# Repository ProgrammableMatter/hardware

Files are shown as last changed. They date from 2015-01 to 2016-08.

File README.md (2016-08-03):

Particle Hardware Repository
----------------------------
Hardware development repository for the particle and related hardware.

## Folder content
* **pcb-projects**: pcb projects
* **freecad**: 3D Models drawn with [FreeCAD](http://www.freecadweb.org/)
* **reflow**: reflow soldering logs, charts and helper

## PCB Projects/Versions
### Particle Version 1.21
| | | |
|---|---|---|
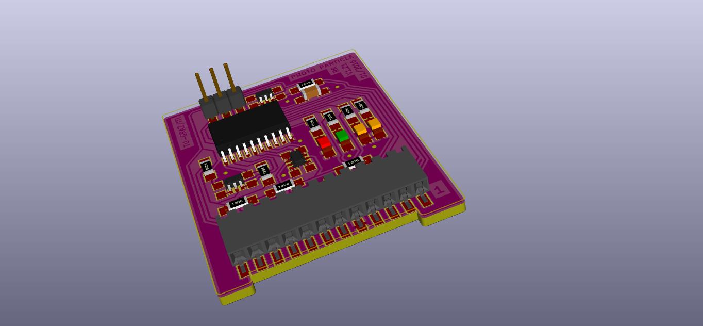
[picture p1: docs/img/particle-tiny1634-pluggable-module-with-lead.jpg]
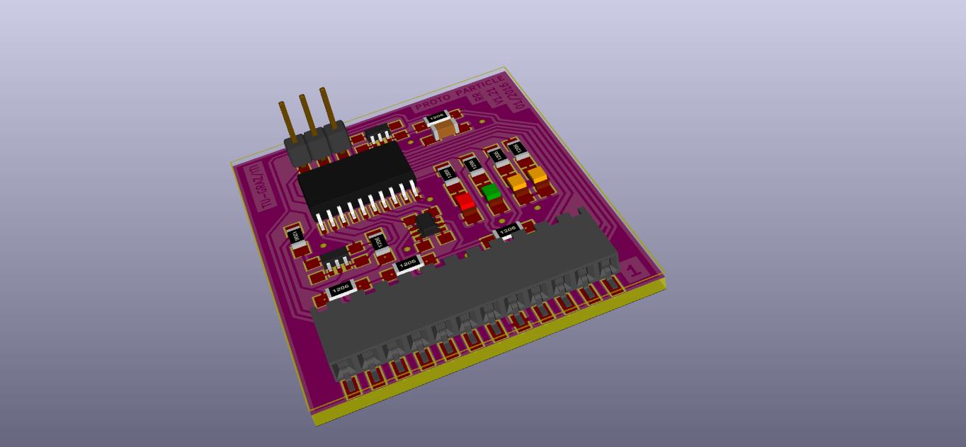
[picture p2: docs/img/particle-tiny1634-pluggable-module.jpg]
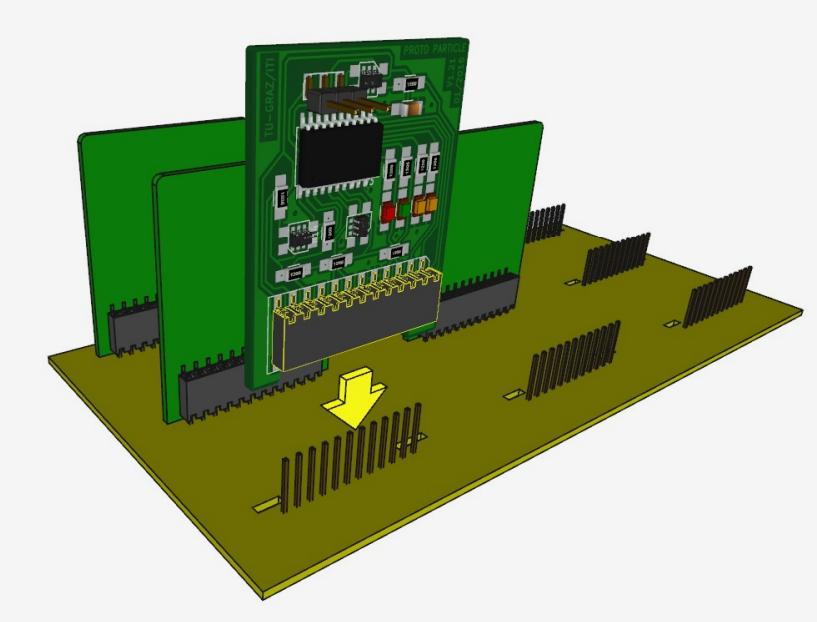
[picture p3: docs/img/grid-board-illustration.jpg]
|  |  |  |
| plugable particle with leads | pluggable particle | grid board illustartion |

### Particle version 1.1

| | | | 
|---|---|---|
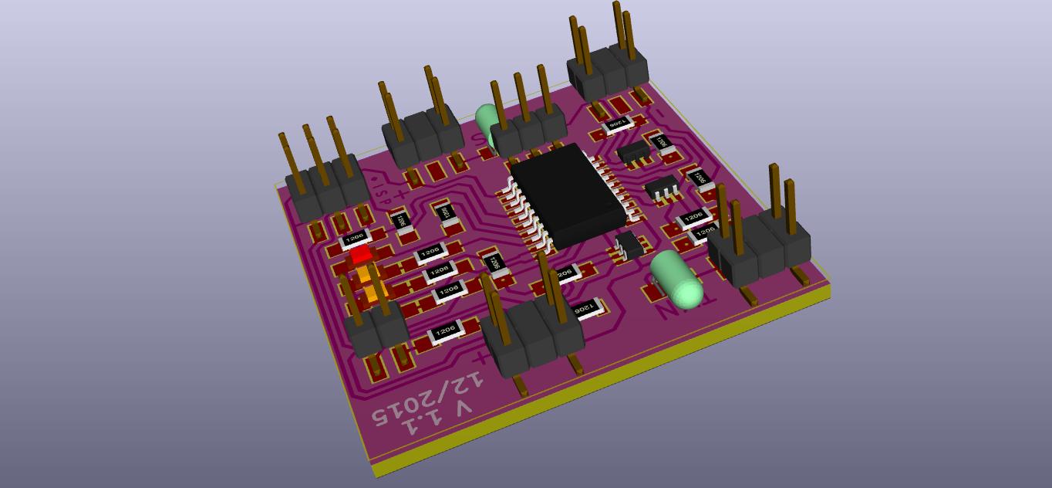
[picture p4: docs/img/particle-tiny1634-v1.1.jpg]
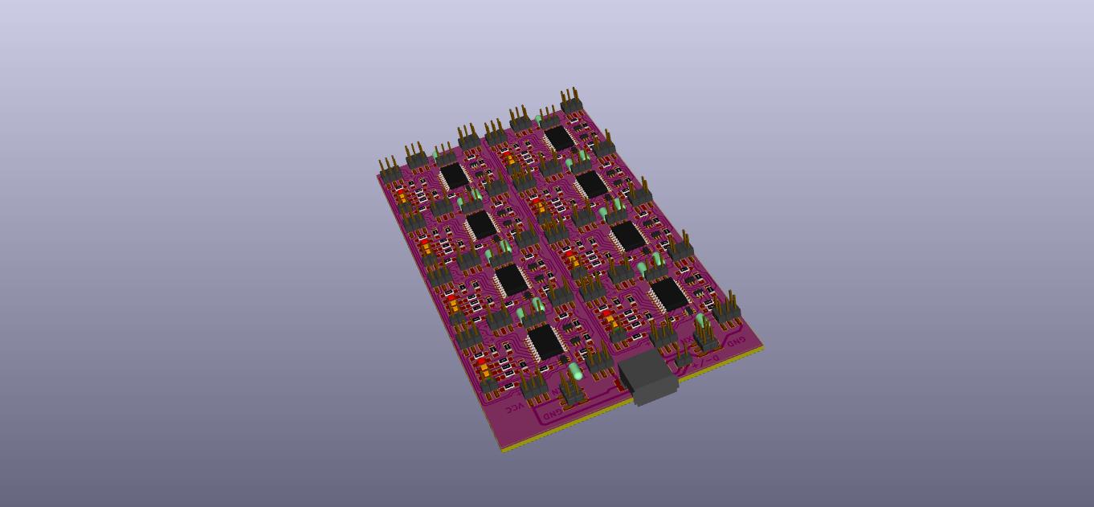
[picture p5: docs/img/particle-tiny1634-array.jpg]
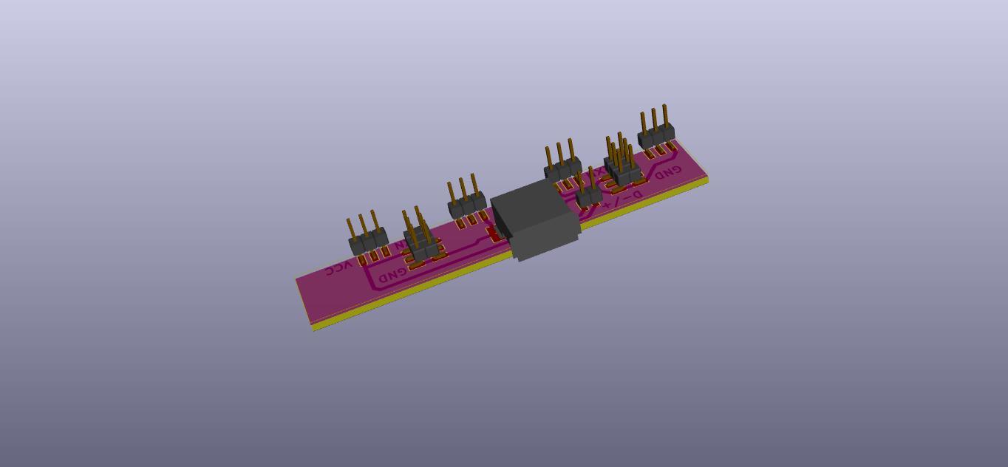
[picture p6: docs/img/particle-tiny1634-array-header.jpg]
||||
| single particle | array example | array header |
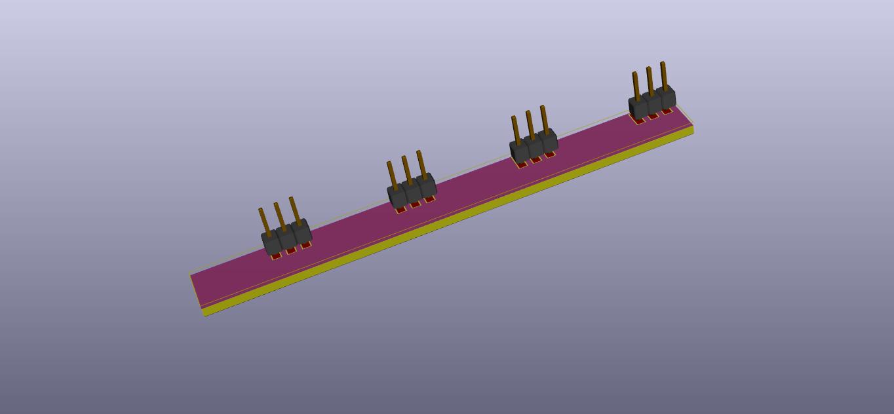
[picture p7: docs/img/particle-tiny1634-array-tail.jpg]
|  | | | 
| array tail | | |

### Particle version 0.9
|   |
|---|
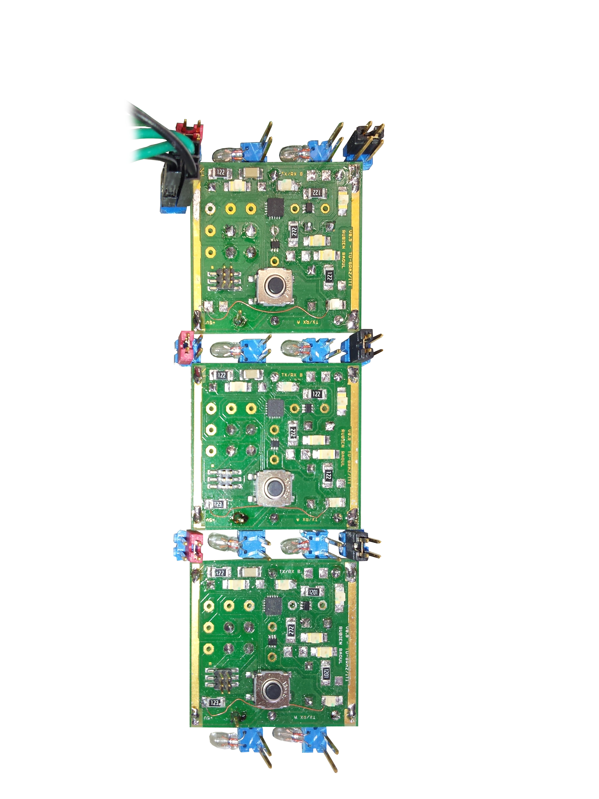
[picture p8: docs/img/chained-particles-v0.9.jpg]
||
| chain example |

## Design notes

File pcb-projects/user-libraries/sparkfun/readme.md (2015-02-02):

SparkFun Electronics Eagle Libraries
====================================

SparkFun Electronics' preferred foot prints using Eagle v6.0 or greater. 
We've spent an enormous amount of time creating and checking these footprints and parts. 
If you enjoy using this library, please buy one of our products at [SparkFun](http://www.sparkfun.com). 
Please also note that we guarantee that there are some messed up footprints in this library. 
We've tried to note which are proven and tested, but by downloading these files, you acknowledge that you are using the files at your own risk. 
We cannot be held responsible for faulty PCBs. 
Always check your parts against a 1:1 printout.

This is the complete SparkFun Electronics default foot prints for Eagle 6.0+. 
We switched to Eagle back in 2006 and have been extremely impressed with its ease of use and flexibility. 
As with any new software, it's like learning a new language and takes time. Do it. Eagle is great. 

How to Use Eagle
----------------

If you need more information about how to use Eagle, checkout our Eagle Tutorials: 

* [Installing an Eagle Library](https://learn.sparkfun.com/tutorials/how-to-install-and-setup-eagle#using-the-sparkfun-libraries)
* [Installing Eagle](https://learn.sparkfun.com/tutorials/how-to-install-and-setup-eagle)
* [Creating Schematics](https://learn.sparkfun.com/tutorials/using-eagle-schematic)
* [Creating Boards](https://learn.sparkfun.com/tutorials/using-eagle-board-layout)
* [Designing Custom Footprints](https://learn.sparkfun.com/tutorials/designing-pcbs-smd-footprints)
* [Creating Footprints from Digital Imagery](https://learn.sparkfun.com/tutorials/making-custom-footprints-in-eagle)

How to use GitHub
-----------------

If you need help getting started using git, check out our GitHub tutorials:
* [Using GitHub](https://learn.sparkfun.com/tutorials/using-github)
* [Using GitHub to Share with SparkFun](https://learn.sparkfun.com/tutorials/using-github-to-share-with-sparkfun)

The library associated with Eagle v5.11 and earlier is found [here](https://github.com/sparkfun/Old-SparkFun-Eagle-Library).

License Information
-------------------

This library is released under the [Creative Commons ShareAlike 4.0 International](https://creativecommons.org/licenses/by-sa/4.0/) license. 
**You are welcome to use this library for commercial purposes.**
For attribution, we ask that when you begin to sell your device using our footprint, you email us with a link to the product being sold. 
We want bragging rights that we helped (in a very small part) to create your 8th world wonder. 
We would like the opportunity to feature your device on our homepage.

Please consider contributing back to this library or others to help the open-source hardware community continue to thrive and grow!

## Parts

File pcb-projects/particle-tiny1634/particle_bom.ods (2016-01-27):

Id | Designator | Package | Quantity | Designation | Supplier and ref
1 | R1124,R1114,R1123,R1113,R1122,R1112,R1121,R124,R114,R123,R113,R122,R112,R121,R124,R114,R123,R113,R122,R112,R121,R1124,R1114,R1123,R1113,R1122,R1112,R1121,R1124,R1114,R1123,R1113,R1122,R1112,R1121,R124,R114,R123,R113,R122,R112,R121,R1124,R1114,R1123,R1113,R1122,R1112,R1121,R124,R114,R123,R113,R122,R112,R121,R124,R114,R123,R113,R122,R112,R121,R1111,R111,R111,R111,R111,R111,R1111,R1111,R1111 | R_1206_HandSoldering | 72 | 0R
2 | FB124,FB114,FB123,FB113,FB122,FB112,FB121,FB111 | SMD-1206_Pol | 8 | TXS-SMA
3 | P124,P114,P123,P113,P122,P112,P121,P111 | CONN-1x3 | 8 | TEST1-3
4 | P124,P114,P123,P113,P122,P112,P121,P111 | CONN-6_4-6 | 8 | RXS
5 | D124,D114,D123,D113,D122,D112,D121,D111 | R_1206_HandSoldering | 8 | STATUS1
6 | D124,D114,D123,D113,D122,D112,D121,D111 | R_1206_HandSoldering | 8 | ERROR
7 | R124,R114,R123,R113,R122,R112,R121,R124,R114,R123,R113,R122,R112,R121,R124,R114,R123,R113,R122,R112,R121,R1124,R1114,R1123,R1113,R1122,R1112,R1121,R124,R114,R123,R113,R122,R112,R121,R111,R1111,R111,R111,R111 | R_1206_HandSoldering | 40 | 1k2
8 | P124,P114,P123,P113,P122,P112,P121,P111 | CONN-6_4-6 | 8 | TXS
9 | CON124,CON114,CON123,CON113,CON122,CON112,CON121,CON111 | CONN-6 | 8 | AVR-ISP-6
10 | P124,P114,P123,P113,P122,P112,P121,P111 | CONN-1x2 | 8 | TRX-CH
11 | D124,D114,D123,D113,D122,D112,D121,D111 | R_1206_HandSoldering | 8 | HB
12 | D124,D114,D123,D113,D122,D112,D121,D111 | R_1206_HandSoldering | 8 | STATUS0
13 | Q-SOUTH124,Q-SOUTH114,Q-SOUTH123,Q-SOUTH113,Q-SOUTH122,Q-SOUTH112,Q-SOUTH121,Q-NORTH124,Q-NORTH114,Q-NORTH123,Q-NORTH113,Q-NORTH122,Q-NORTH112,Q-NORTH121,Q-CHAIN124,Q-CHAIN114,Q-CHAIN123,Q-CHAIN113,Q-CHAIN122,Q-CHAIN112,Q-CHAIN121,Q-NORTH111,Q-CHAIN111,Q-SOUTH111 | SOT-26 | 24 | DMC2700UDM-7
14 | IC124,IC114,IC123,IC113,IC122,IC112,IC121,IC111 | SOIC-20_7.5x12.8mm_Pitch1.27mm | 8 | ATTINY1634-SU
15 | P124,P114,P123,P113,P122,P112,P121,P111 | CONN-6_1-3 | 8 | TXN
16 | FB124,FB114,FB123,FB113,FB122,FB112,FB121,FB111 | SMD-1206_Pol | 8 | TXN-SMA
17 | P124,P114,P123,P113,P122,P112,P121,P111 | CONN-6_1-3 | 8 | RXN
18 | 1k2/124,1k2/114,1k2/123,1k2/113,1k2/122,1k2/112,1k2/121,1k2/111 | R_1206 | 8 | 1k2
19 | P3 | usb-30-right-angle-true-smt | 1 | USB_A | x
20 | P6 | CONN-6_4-6 | 1 | CHAIN2-TX | x
21 | P1 | CONN-6_4-6 | 1 | CHAIN1-TX | x
22 | P7 | CONN-6_4-6 | 1 | CHAIN2-RX | x
23 | P2 | CONN-6_4-6 | 1 | CHAIN1-RX | x
24 | P4 | CONN-6 | 1 | PWR-WEST | x
25 | P5 | CONN-6 | 1 | PWR-EAST | x
26 | P8 | CONN-1x2 | 1 | RS232 | x
27 | P1,P2,P3,P4 | CONN-6_1-3 | 4 | CONN_02X03 | x
 |  |  | Reference | Value | supplyer | price | needed pcs |  |  | pgks | Price / entity | price total
 |  |  | CON1 | AVR-ISP-6 | http://at.rs-online.com/web/p/leiterplatten-header/5286417/ | 2row-20pole-10pcs/pkg 10-40pcs 2.177 | 13,00 |  |  | 2,00 | 22,20 | 44,40
 |  |  | D1 | HB | http://at.rs-online.com/web/p/leds-sichtbares-licht/7269225/ | 25-100pcs 0.154 | 16,00 |  |  | 16,00 | 3,85 | 61,60
 |  |  | D2 | STATUS0 | http://at.rs-online.com/web/p/leds-sichtbares-licht/7269215/ | 25-100pcs 0.14 | 2x8 |  |  | 2,00 | 3,5 | 7,00
 |  |  | D4 | ERROR | http://at.rs-online.com/web/p/leds-sichtbares-licht/7269212/ | 25-100pcs 0.197 | 1x8 |  |  | 1,00 | 4,925 | 4,93
 |  |  | FB1 | TXN-SMA | http://at.rs-online.com/web/p/anzeigen-gluehlampen/0106458/ | <240pcs 0.733 | 2x8 |  |  | 3,00 | 7,33 | 21,99
 |  |  | IC1 | ATTINY1634-SU | http://at.rs-online.com/web/p/mikrocontroller/7617703/ | rs attiny1634R-su 2-8pcs 1.84 >10pcs 1.725 farnell attiny1634-su <10pcs 1.44 <25pcs 1.35 | 1x8 |  |  | 8,00 | 3,68 | 29,44
 |  |  | P6 | TEST1-3 | http://at.rs-online.com/web/p/leiterplatten-header/0155901/ | 5pcs-40pol/pkg pcs 1.324 | 8,00 |  |  | 3,00 | 1,35 | 4,04
 |  |  | Q-NORTH1 | DMC2700UDM-7 | http://at.rs-online.com/web/p/transistoren-mosfet/8232918/ | 20-80pcs 0.1291 >100pcs 0.132 | 2x8+2 |  |  | 2,00 | 2,64 | 5,28
 |  |  | R14 | 1k2 | http://at.rs-online.com/web/p/smd-widerstande/8071158/ | < 5pkg @ 100pcs 1.72 per pkg | 48,00 |  |  | 1,00 | 1,77 | 1,77
 |  |  |  | 0R | http://at.rs-online.com/web/p/smd-widerstande/7409104/ | <450pcs 0.016 | 80,00 |  |  | 4,00 | 0,80 | 3,20
 |  |  |  | usb a smd | http://at.farnell.com/multicomp/usb-a-s-ra-tsmt/usb-3-0-buchse-typ-a-smd/dp/2112370 | < 50pcs 0,578 | 2,00 |  |  | 1,00 | 0,578 | 0,58
 |  |  |  |  | supplyer |  |  | #pcs | €/pcs | €/pkg
 |  |  |  |  | http://at.rs-online.com/web/p/leiterplatten-header/5286417/ |  |  | 20,00 | 2,22 | 22,20
 |  |  |  |  | http://at.rs-online.com/web/p/leds-sichtbares-licht/7269225/ |  |  | 16,00 | 0,154 | 3,85
 |  |  |  |  | http://at.rs-online.com/web/p/leds-sichtbares-licht/7269215/ |  |  | 32,00 | 0,14 | 3,5
 |  |  |  |  | http://at.rs-online.com/web/p/leds-sichtbares-licht/7269212/ |  |  | 16,00 | 0,197 | 4,925
 |  |  |  |  | http://at.rs-online.com/web/p/anzeigen-gluehlampen/0106458/ |  |  | 30,00 | 0,73 | 7,33
 |  |  |  |  | http://at.rs-online.com/web/p/mikrocontroller/7617703/ |  |  | 16,00 | 1,84 | 3,68
 |  |  |  |  | http://at.rs-online.com/web/p/leiterplatten-header/0155901/ |  |  | 16,00 | 1,35 | 6,73
 |  |  |  |  | http://at.rs-online.com/web/p/transistoren-mosfet/8232918/ |  |  | 36,00 | 0,13 | 2,64
 |  |  |  |  | http://at.rs-online.com/web/p/smd-widerstande/8071158/ |  |  | 84,00 | 0,02 | 1,77
 |  |  |  |  | http://at.rs-online.com/web/p/smd-widerstande/7409104/ |  |  | 144,00 | 0,016 | 0,80
 |  |  |  |  | http://at.farnell.com/multicomp/usb-a-s-ra-tsmt/usb-3-0-buchse-typ-a-smd/dp/2112370 |  |  | 2,00 | 0,578 | 5,78
 |  |  |  |  | http://at.rs-online.com/web/p/usb-typ-a-steckverbinder/7187214/ |  |  | 2,00 | 2,87

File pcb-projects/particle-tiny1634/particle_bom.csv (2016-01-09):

Reference | Value | supplyer | price | needed pcs | needed pcs/pkg | Price / entity | price total
CON1 | AVR-ISP-6 | http://at.rs-online.com/web/p/leiterplatten-header/5286417/ | 2row-20pole-10pcs/pkg 10-40pcs 2.177 | 6pcs for 8 | 1 | 2,177 | 2,177
D1 | HB | http://at.rs-online.com/web/p/leds-sichtbares-licht/7269225/ | 25-100pcs 0.154 | 1x8 | 8 | 0,154 | 1,232
D2 | STATUS0 | http://at.rs-online.com/web/p/leds-sichtbares-licht/7269215/ | 25-100pcs 0.14 | 2x8 | 16 | 0,14 | 2,24
D4 | ERROR | http://at.rs-online.com/web/p/leds-sichtbares-licht/7269212/ | 25-100pcs 0.197 | 1x8 | 8 | 0,197 | 1,576
FB1 | TXN-SMA | http://at.rs-online.com/web/p/anzeigen-gluehlampen/0106458/ | <240pcs 0.733 | 2x8 | 16 | 0,733 | 11,728
IC1 | ATTINY1634-SU | http://at.rs-online.com/web/p/mikrocontroller/7617703/ | rs attiny1634R-su 2-8pcs 1.84 >10pcs 1.725 farnell attiny1634-su <10pcs 1.44 <25pcs 1.35 | 1x8 | 8 | 1,84 | 14,72
P6 | TEST1-3 | http://at.rs-online.com/web/p/leiterplatten-header/0155901/ | 5pcs-40pol/pkg pcs 1.324 | 1.6pcs | 1 | 6,6 | 6,6
Q-NORTH1 | DMC2700UDM-7 | http://at.rs-online.com/web/p/transistoren-mosfet/8232918/ | 20-80pcs 0.1291 >100pcs 0.132 | 2x8+2 | 18 | 0,132 | 2,376
R14 | 1k2 | http://at.rs-online.com/web/p/smd-widerstande/8071158/ | < 5pkg @ 100pcs 1.72 per pkg | 5x8 | 1 | 1,7 | 1,7
 |  | http://at.rs-online.com/web/p/smd-widerstande/7409104/ | <450pcs 0.016 | 7x8+2x2 | 60 | 0,016 | 0,96
 |  |  |  |  |  |  | 45,309 | = total sum
 | usb a smd | http://at.farnell.com/multicomp/usb-a-s-ra-tsmt/usb-3-0-buchse-typ-a-smd/dp/2112370 | < 50pcs 0,578 | 1 | 10 | 0,578 | 5,8

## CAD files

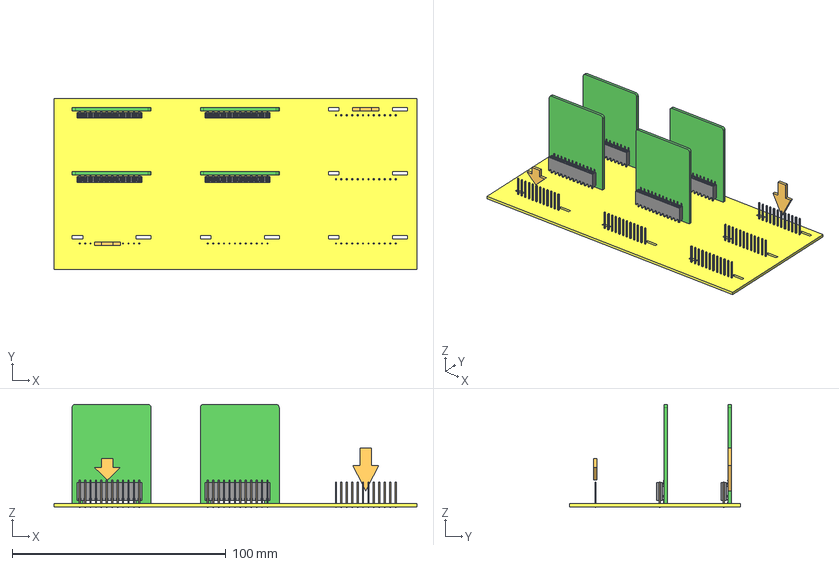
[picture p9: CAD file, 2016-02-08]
freecad/proto-pcb-gridboard-sketch.fcstd
170.0 x 80.0 x 48.4 mm
grid-board
Clone of Clone of Pad003

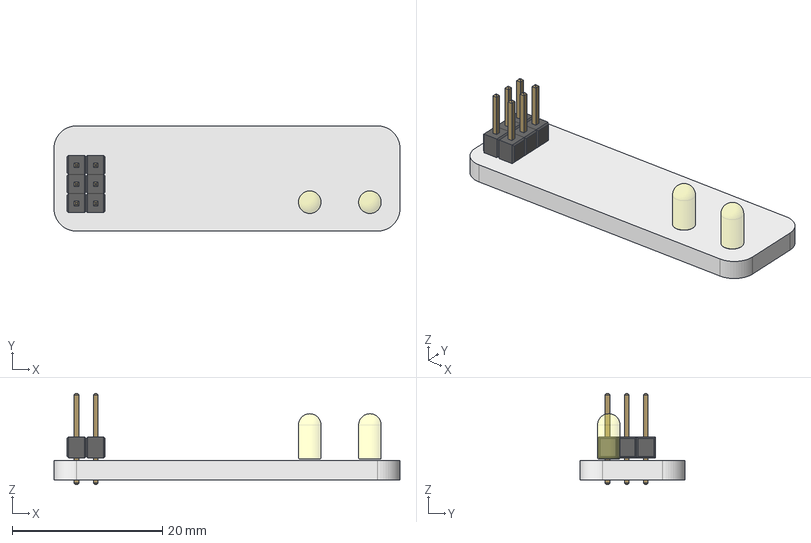
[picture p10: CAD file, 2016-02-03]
freecad/grid-board-particle-connector.fcstd
46.0 x 14.0 x 12.2 mm
bulb001
bulb002

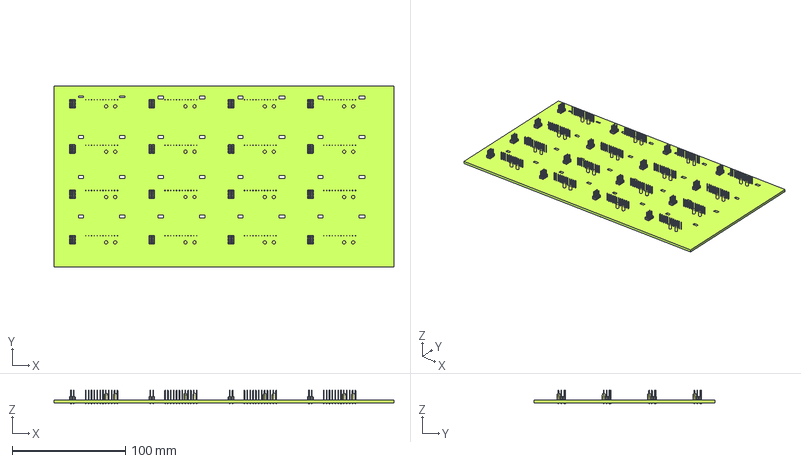
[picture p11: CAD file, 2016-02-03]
freecad/proto-pcb-gridboard-vis.fcstd
300.0 x 160.0 x 12.2 mm

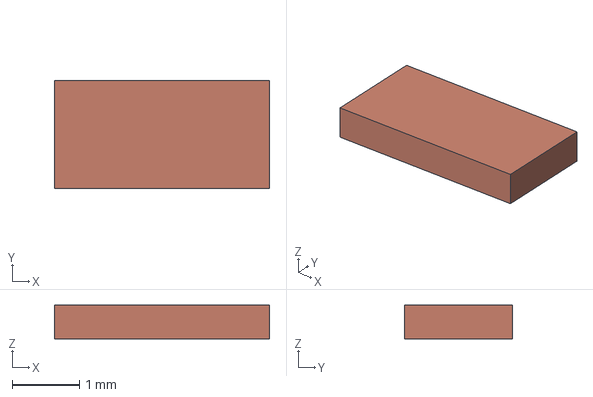
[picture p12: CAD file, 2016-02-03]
freecad/led-smd-1206.fcstd
3.20 x 1.60 x 0.5 mm

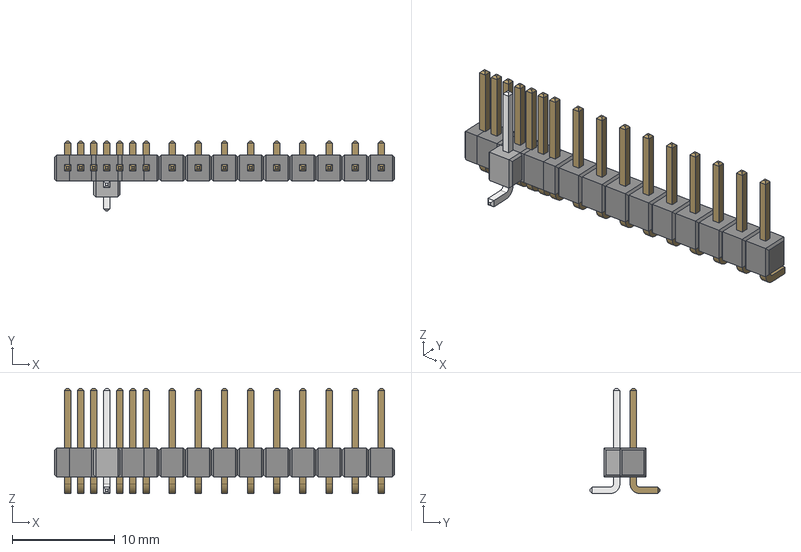
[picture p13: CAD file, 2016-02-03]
freecad/pin-header-254mm.fcstd
33.0 x 6.76 x 10.2 mm
pin
spacer
1p2 (Mirror #1)
1p3 (Mirror #2)
1p4 (Mirror #3)
1s2 (Mirror #4)
1s3 (Mirror #5)
1s4 (Mirror #6)
1x2p-2missing (Mirror #7)

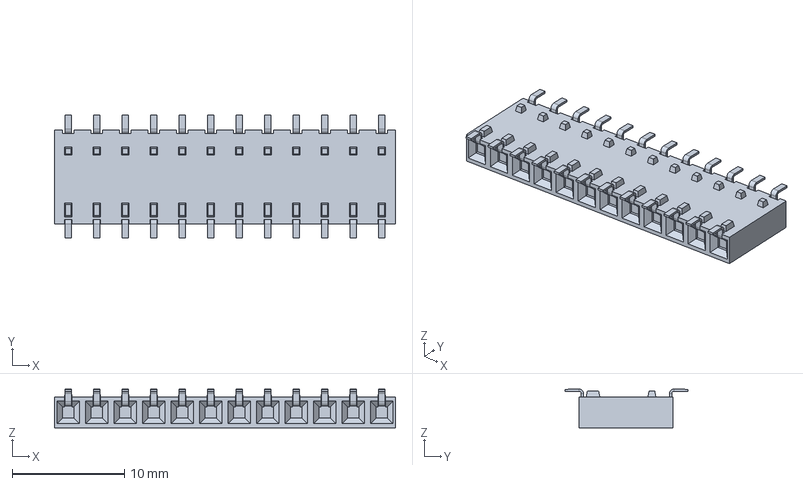
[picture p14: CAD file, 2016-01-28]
freecad/conn_fci_smt_right_angled-71607-312LFc.stp
30.4 x 10.9 x 3.47 mm

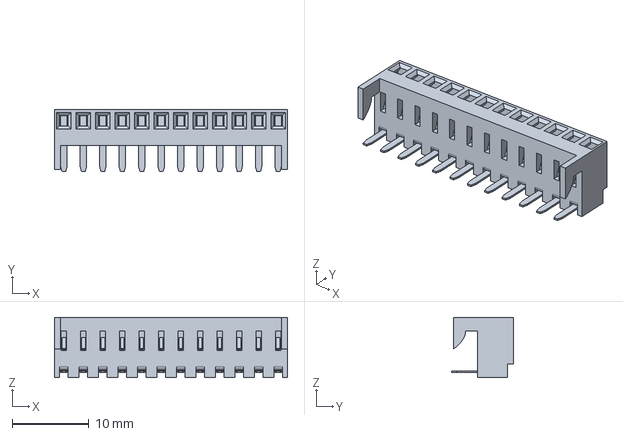
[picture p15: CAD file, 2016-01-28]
freecad/conn_molex-01x12-right-angled-38-00-1342-038001342.stp
30.4 x 8.05 x 7.87 mm

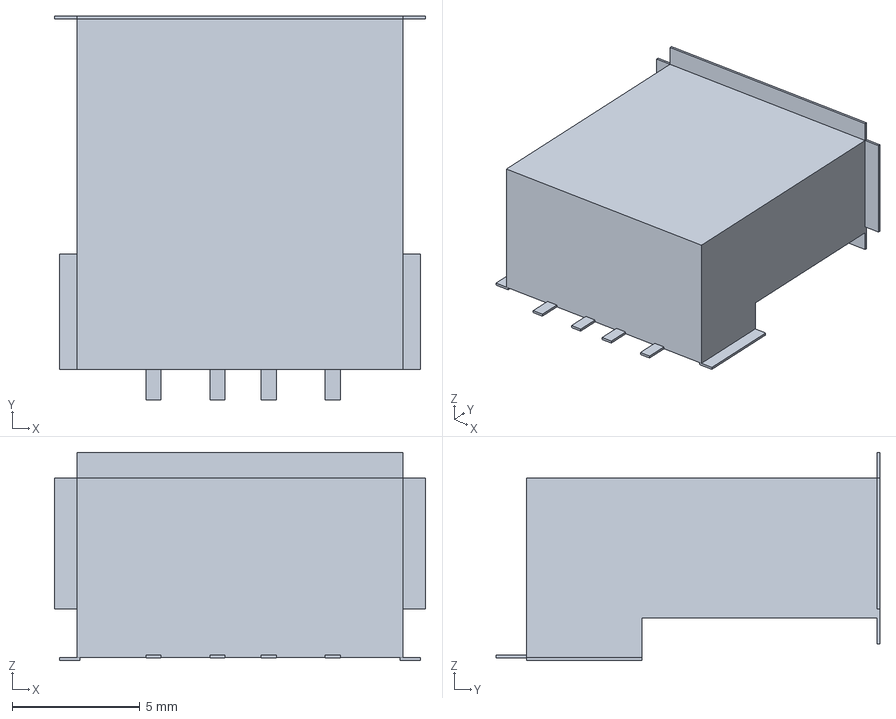
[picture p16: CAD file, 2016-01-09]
freecad/usb-multicomp.fcstd
14.5 x 15.0 x 8.14 mm

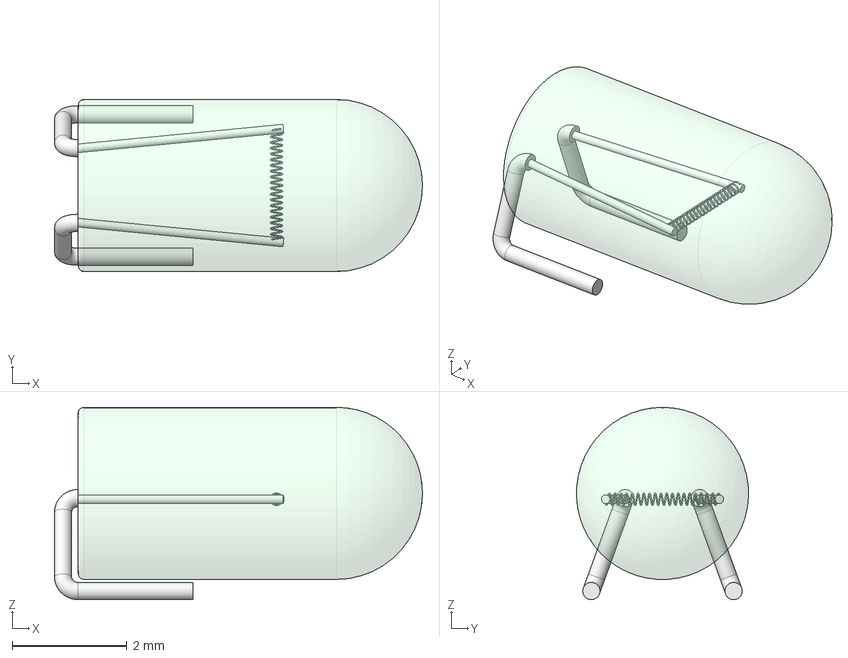
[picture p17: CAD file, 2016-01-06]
freecad/lightbulb-3x6.fcstd
6.41 x 3.00 x 3.35 mm
wire2i
wire1
wire2
wire2i (Mirror #1)
bulb

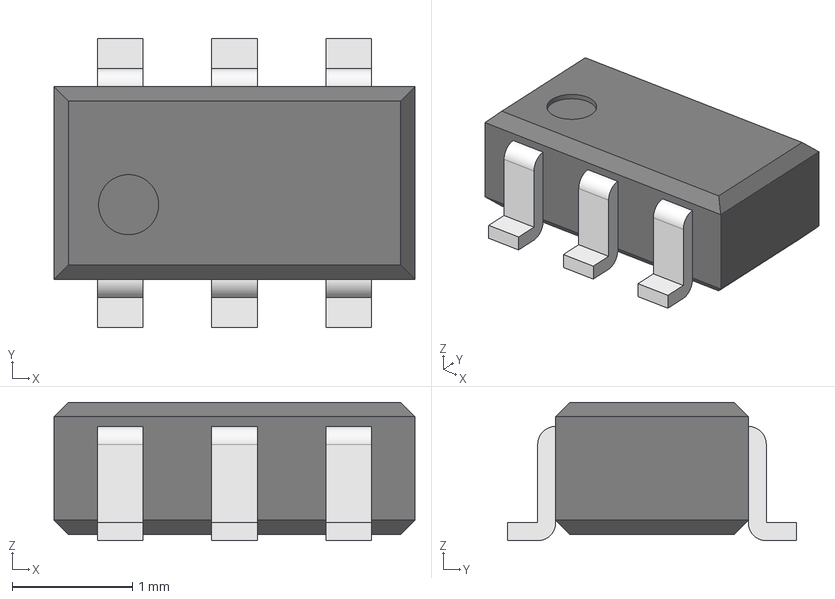
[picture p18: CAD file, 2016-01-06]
freecad/sot26.fcstd
3.00 x 2.40 x 1.15 mm
Array (Mirror #1)

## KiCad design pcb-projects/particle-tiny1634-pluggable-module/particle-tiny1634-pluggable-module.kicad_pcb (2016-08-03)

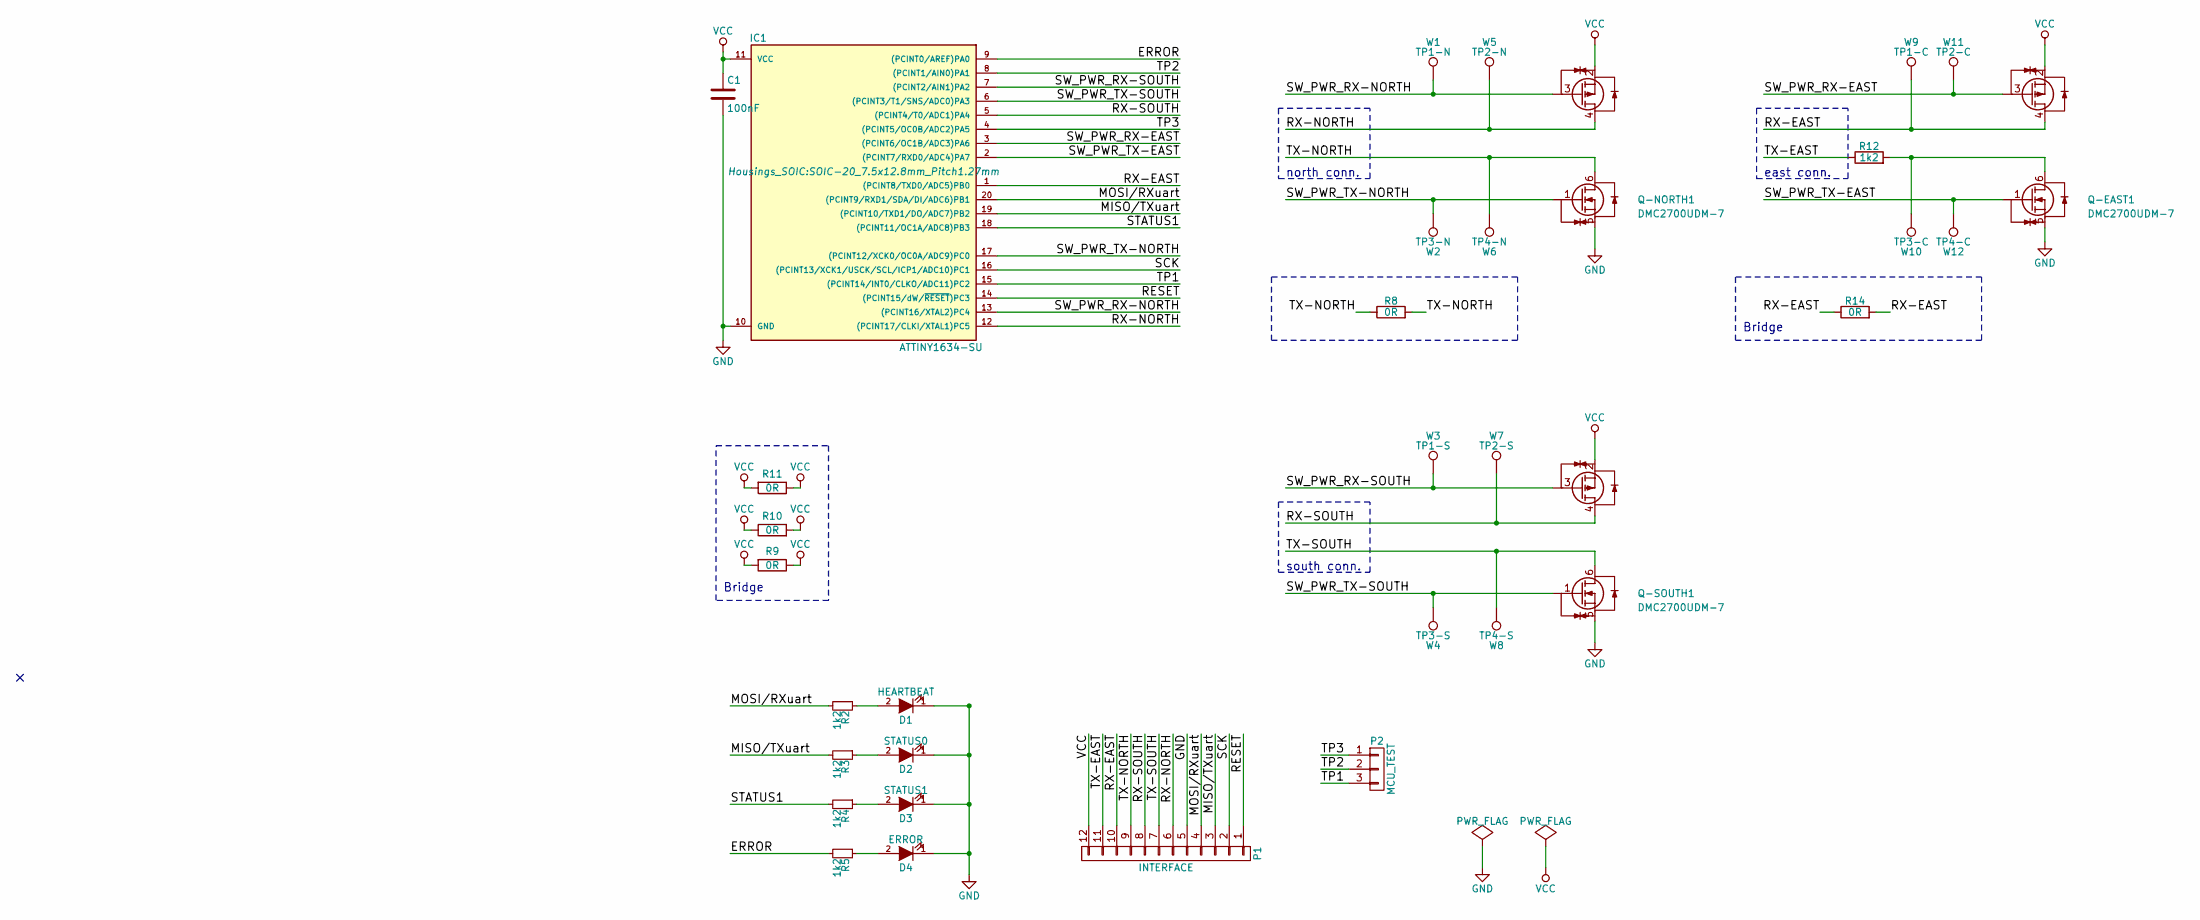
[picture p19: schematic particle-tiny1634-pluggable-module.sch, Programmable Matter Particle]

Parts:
C1: 100nF; C_1206_HandSoldering
D1: HEARTBEAT; R_1206_HandSoldering
D2: STATUS0; R_1206_HandSoldering
D3: STATUS1; R_1206_HandSoldering
D4: ERROR; R_1206_HandSoldering
IC1: ATTINY1634-SU; SOIC-20_7.5x12.8mm_Pitch1.27mm
P1: INTERFACE; 01x12-FCI-71607-312LF
P2: MCU_TEST; CONN-1x3
Q-EAST1: DMC2700UDM-7; SOT-26
Q-NORTH1: DMC2700UDM-7; SOT-26
Q-SOUTH1: DMC2700UDM-7; SOT-26
R2, R3, R4, R5, R12: 1k2; R_1206_HandSoldering
R8, R9, R10, R11, R14: 0R; R_1206_HandSoldering
W1: TP1-N; Measurement_Point_Square-SMD-Pad_Small
W2: TP3-N; Measurement_Point_Square-SMD-Pad_Small
W3: TP1-S; Measurement_Point_Square-SMD-Pad_Small
W4: TP3-S; Measurement_Point_Square-SMD-Pad_Small
W5: TP2-N; Measurement_Point_Square-SMD-Pad_Small
W6: TP4-N; Measurement_Point_Square-SMD-Pad_Small
W7: TP2-S; Measurement_Point_Square-SMD-Pad_Small
W8: TP4-S; Measurement_Point_Square-SMD-Pad_Small
W9: TP1-C; Measurement_Point_Square-SMD-Pad_Small
W10: TP3-C; Measurement_Point_Square-SMD-Pad_Small
W11: TP2-C; Measurement_Point_Square-SMD-Pad_Small
W12: TP4-C; Measurement_Point_Square-SMD-Pad_Small

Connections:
/ERROR: IC1.9 ((PCINT0/AREF)PA0), R5.2
/MISO/TXuart: IC1.19 ((PCINT10/TXD1/DO/ADC7)PB2), P1.3, R3.2
/MOSI/RXuart: IC1.20 ((PCINT9/RXD1/SDA/DI/ADC6)PB1), P1.4, R2.2
/RESET: IC1.14 ((PCINT15/dW/~RESET~)PC3), P1.1
/RX-EAST: IC1.1 ((PCINT8/TXD0/ADC5)PB0), P1.10, Q-EAST1.4 (D2), R14.1, R14.2, W9.1
/RX-NORTH: IC1.12 ((PCINT17/CLKI/XTAL1)PC5), P1.6, Q-NORTH1.4 (D2), W5.1
/RX-SOUTH: IC1.5 ((PCINT4/T0/ADC1)PA4), P1.8, Q-SOUTH1.4 (D2), W7.1
/SCK: IC1.16 ((PCINT13/XCK1/USCK/SCL/ICP1/ADC10)PC1), P1.2
/STATUS1: IC1.18 ((PCINT11/OC1A/ADC8)PB3), R4.2
/SW_PWR_RX-EAST: IC1.3 ((PCINT6/OC1B/ADC3)PA6), Q-EAST1.3 (G2), W11.1
/SW_PWR_RX-NORTH: IC1.13 ((PCINT16/XTAL2)PC4), Q-NORTH1.3 (G2), W1.1
/SW_PWR_RX-SOUTH: IC1.7 ((PCINT2/AIN1)PA2), Q-SOUTH1.3 (G2), W3.1
/SW_PWR_TX-EAST: IC1.2 ((PCINT7/RXD0/ADC4)PA7), Q-EAST1.1 (G1), W12.1
/SW_PWR_TX-NORTH: IC1.17 ((PCINT12/XCK0/OC0A/ADC9)PC0), Q-NORTH1.1 (G1), W2.1
/SW_PWR_TX-SOUTH: IC1.6 ((PCINT3/T1/SNS/ADC0)PA3), Q-SOUTH1.1 (G1), W4.1
/TP1: IC1.15 ((PCINT14/INT0/CLKO/ADC11)PC2), P2.3
/TP2: IC1.8 ((PCINT1/AIN0)PA1), P2.2
/TP3: IC1.4 ((PCINT5/OC0B/ADC2)PA5), P2.1
/TX-EAST: P1.11, R12.1
/TX-NORTH: P1.9, Q-NORTH1.6 (D1), R8.1, R8.2, W6.1
/TX-SOUTH: P1.7, Q-SOUTH1.6 (D1), W8.1
GND: C1.2, D1.1 (K), D2.1 (K), D3.1 (K), D4.1 (K), IC1.10 (GND), P1.5, Q-EAST1.5 (S1), Q-NORTH1.5 (S1), Q-SOUTH1.5 (S1)
unnamed: D1.2 (A), R2.1
unnamed: D2.2 (A), R3.1
unnamed: D3.2 (A), R4.1
unnamed: D4.2 (A), R5.1
unnamed: Q-EAST1.6 (D1), R12.2, W10.1
VCC: C1.1, IC1.11 (VCC), P1.12, Q-EAST1.2 (S2), Q-NORTH1.2 (S2), Q-SOUTH1.2 (S2), R9.1, R9.2, R10.1, R10.2, R11.1, R11.2

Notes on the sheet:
Bridge
north conn.
south conn.
east conn.

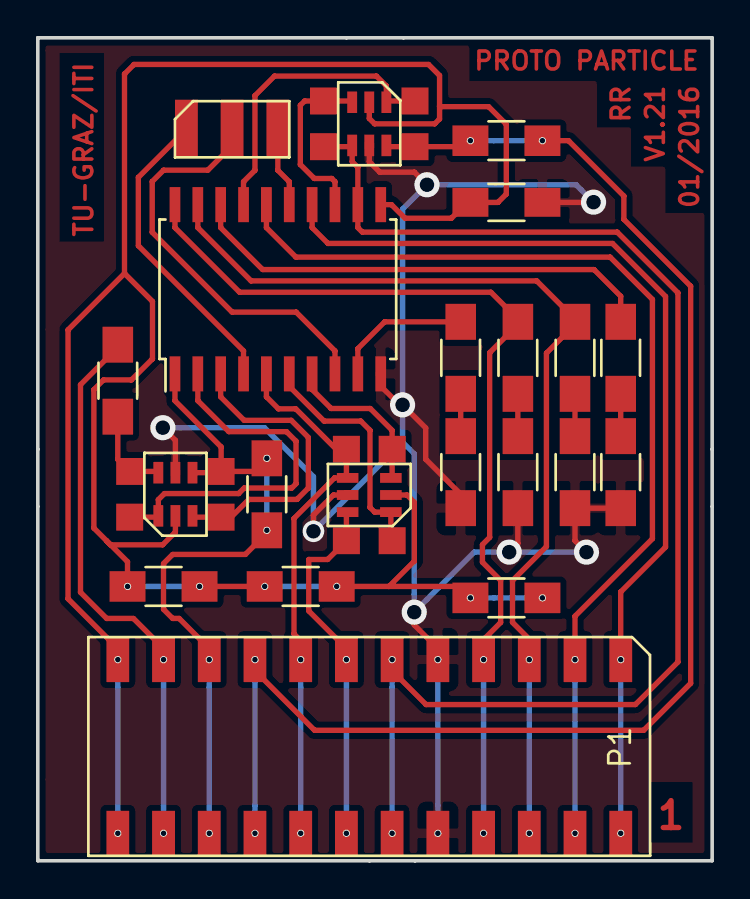
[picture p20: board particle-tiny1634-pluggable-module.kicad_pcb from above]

Board: 2 copper layers, 37.5 x 45.7 mm, 33 parts (0 on the bottom side), 28 nets.

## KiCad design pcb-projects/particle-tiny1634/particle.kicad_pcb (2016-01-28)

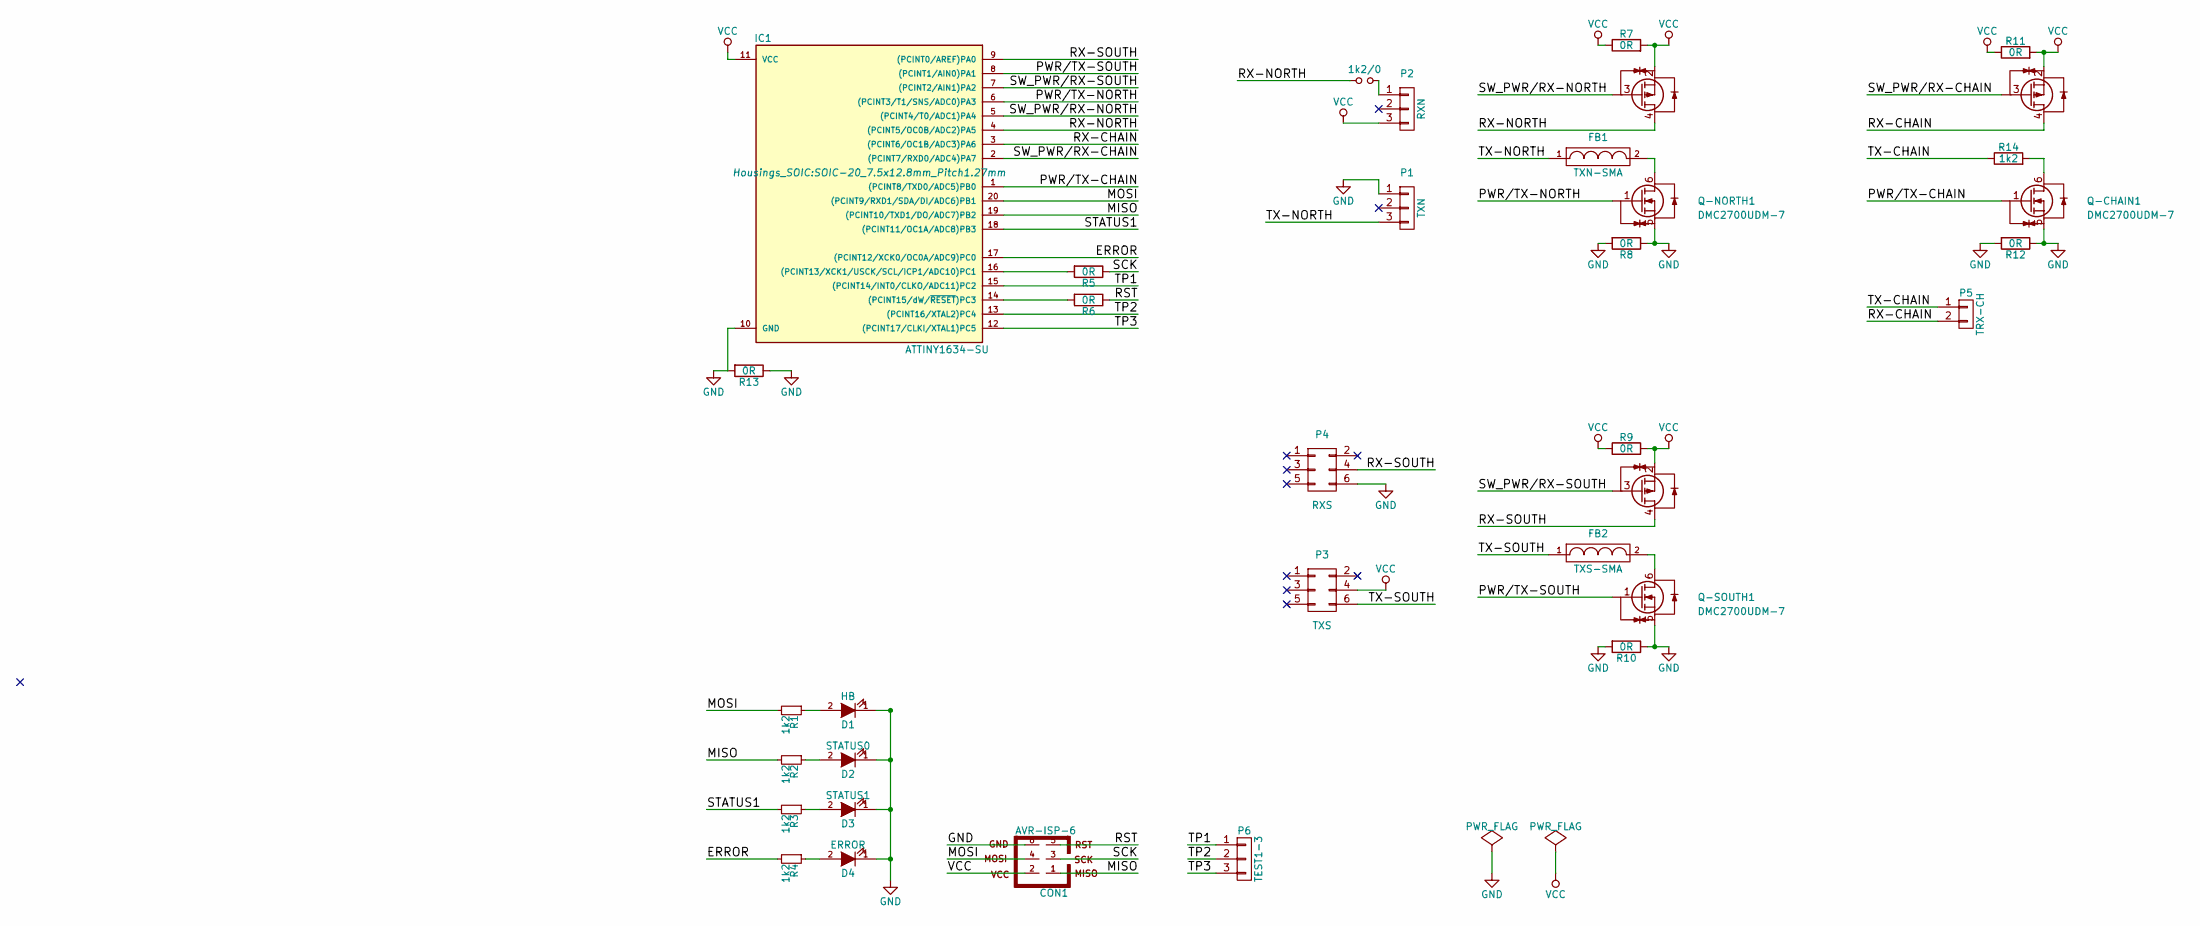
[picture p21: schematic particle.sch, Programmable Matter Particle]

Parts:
1k2/0: 1k2; R_1206
CON1: AVR-ISP-6; CONN-6
D1: HB; R_1206_HandSoldering
D2: STATUS0; R_1206_HandSoldering
D3: STATUS1; R_1206_HandSoldering
D4: ERROR; R_1206_HandSoldering
FB1: TXN-SMA; SMD-1206_Pol
FB2: TXS-SMA; SMD-1206_Pol
IC1: ATTINY1634-SU; SOIC-20_7.5x12.8mm_Pitch1.27mm
P1: TXN; CONN-6_1-3
P2: RXN; CONN-6_1-3
P3: TXS; CONN-6_4-6
P4: RXS; CONN-6_4-6
P5: TRX-CH; CONN-1x2
P6: TEST1-3; CONN-1x3
Q-CHAIN1: DMC2700UDM-7; SOT-26
Q-NORTH1: DMC2700UDM-7; SOT-26
Q-SOUTH1: DMC2700UDM-7; SOT-26
R1, R2, R3, R4, R14: 1k2; R_1206_HandSoldering
R5, R6, R7, R8, R9, R10, R11, R12, R13: 0R; R_1206_HandSoldering

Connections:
/ERROR: IC1.17 ((PCINT12/XCK0/OC0A/ADC9)PC0), R4.2
/MISO: CON1.1, IC1.19 ((PCINT10/TXD1/DO/ADC7)PB2), R2.2
/MOSI: CON1.4, IC1.20 ((PCINT9/RXD1/SDA/DI/ADC6)PB1), R1.2
/PWR/TX-CHAIN: IC1.1 ((PCINT8/TXD0/ADC5)PB0), Q-CHAIN1.1 (G1)
/PWR/TX-NORTH: IC1.6 ((PCINT3/T1/SNS/ADC0)PA3), Q-NORTH1.1 (G1)
/PWR/TX-SOUTH: IC1.8 ((PCINT1/AIN0)PA1), Q-SOUTH1.1 (G1)
/RST: CON1.5, R6.1
/RX-CHAIN: IC1.3 ((PCINT6/OC1B/ADC3)PA6), P5.2, Q-CHAIN1.4 (D2)
/RX-NORTH: 1k2/0.1, IC1.4 ((PCINT5/OC0B/ADC2)PA5), Q-NORTH1.4 (D2)
/RX-SOUTH: IC1.9 ((PCINT0/AREF)PA0), P4.4, Q-SOUTH1.4 (D2)
/SCK: CON1.3, R5.1
/STATUS1: IC1.18 ((PCINT11/OC1A/ADC8)PB3), R3.2
/SW_PWR/RX-CHAIN: IC1.2 ((PCINT7/RXD0/ADC4)PA7), Q-CHAIN1.3 (G2)
/SW_PWR/RX-NORTH: IC1.5 ((PCINT4/T0/ADC1)PA4), Q-NORTH1.3 (G2)
/SW_PWR/RX-SOUTH: IC1.7 ((PCINT2/AIN1)PA2), Q-SOUTH1.3 (G2)
/TP1: IC1.15 ((PCINT14/INT0/CLKO/ADC11)PC2), P6.1
/TP2: IC1.13 ((PCINT16/XTAL2)PC4), P6.2
/TP3: IC1.12 ((PCINT17/CLKI/XTAL1)PC5), P6.3
/TX-CHAIN: P5.1, R14.1
/TX-NORTH: FB1.1, P1.3
/TX-SOUTH: FB2.1, P3.6
GND: CON1.6, D1.1 (K), D2.1 (K), D3.1 (K), D4.1 (K), IC1.10 (GND), P1.1, P4.6, Q-CHAIN1.5 (S1), Q-NORTH1.5 (S1), Q-SOUTH1.5 (S1), R8.1, R8.2, R10.1, R10.2, R12.1, R12.2, R13.1, R13.2
unnamed: 1k2/0.2, P2.1
unnamed: D1.2 (A), R1.1
unnamed: D2.2 (A), R2.1
unnamed: D3.2 (A), R3.1
unnamed: D4.2 (A), R4.1
unnamed: FB1.2, Q-NORTH1.6 (D1)
unnamed: FB2.2, Q-SOUTH1.6 (D1)
unnamed: IC1.14 ((PCINT15/dW/~RESET~)PC3), R6.2
unnamed: IC1.16 ((PCINT13/XCK1/USCK/SCL/ICP1/ADC10)PC1), R5.2
unnamed: Q-CHAIN1.6 (D1), R14.2
VCC: CON1.2, IC1.11 (VCC), P2.3, P3.4, Q-CHAIN1.2 (S2), Q-NORTH1.2 (S2), Q-SOUTH1.2 (S2), R7.1, R7.2, R9.1, R9.2, R11.1, R11.2

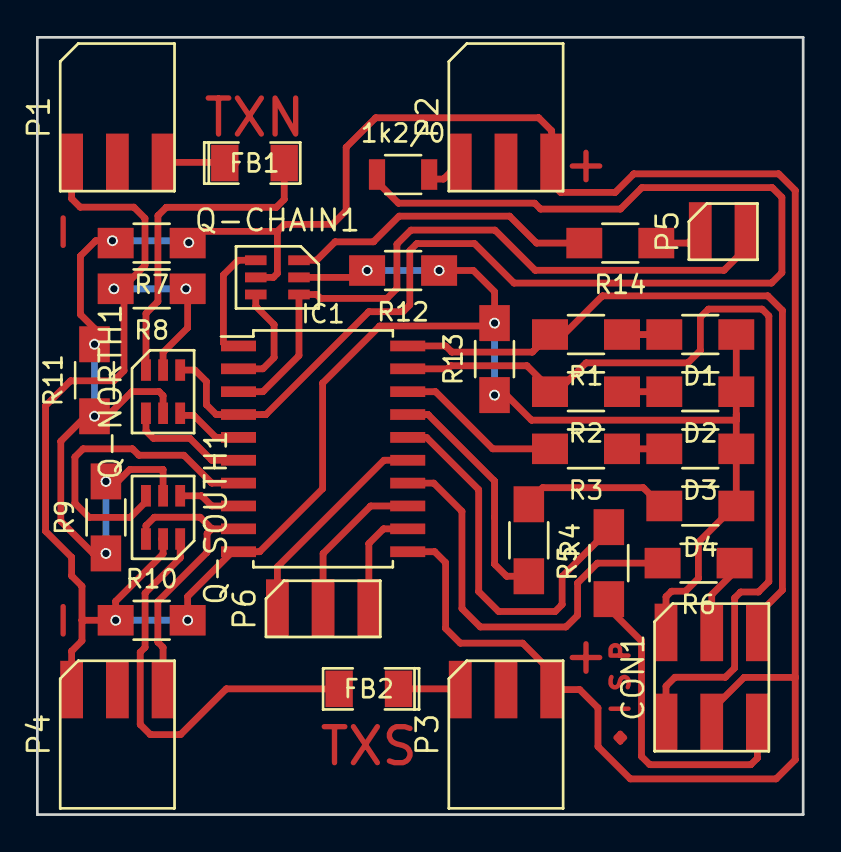
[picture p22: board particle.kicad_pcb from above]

Board: 2 copper layers, 42.5 x 43.2 mm, 32 parts (0 on the bottom side), 33 nets.

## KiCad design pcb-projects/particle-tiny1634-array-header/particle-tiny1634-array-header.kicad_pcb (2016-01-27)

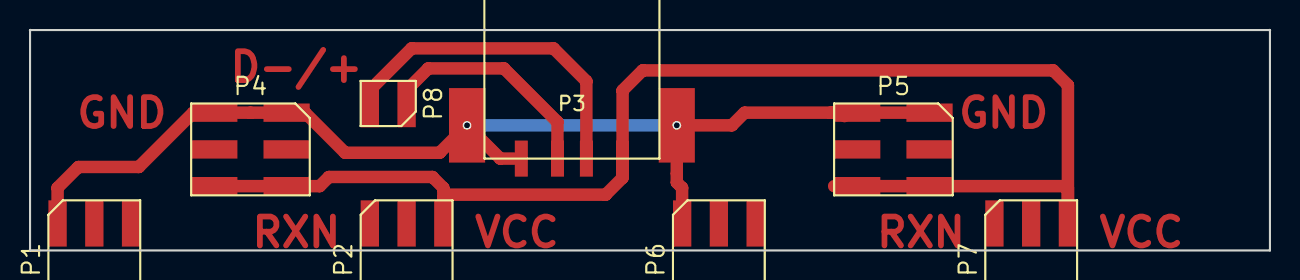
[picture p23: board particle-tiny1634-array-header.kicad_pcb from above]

Board: 2 copper layers, 85.7 x 15.2 mm, 8 parts (0 on the bottom side), 4 nets.

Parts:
P1: CHAIN1-TX; CONN-6_4-6
P2: CHAIN1-RX; CONN-6_4-6
P3: USB_A; usb-30-right-angle-true-smt
P4: PWR-WEST; CONN-6
P5: PWR-EAST; CONN-6
P6: CHAIN2-TX; CONN-6_4-6
P7: CHAIN2-RX; CONN-6_4-6
P8: RS232; CONN-1x2

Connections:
/D+: P3.3, P8.1
/D-: P3.2, P8.2
GND: P1.6, P3.4, P3.5, P4.1, P4.6, P5.1, P5.6, P6.6
VCC: P2.4, P3.1, P4.3, P4.4, P5.3, P5.4, P7.4

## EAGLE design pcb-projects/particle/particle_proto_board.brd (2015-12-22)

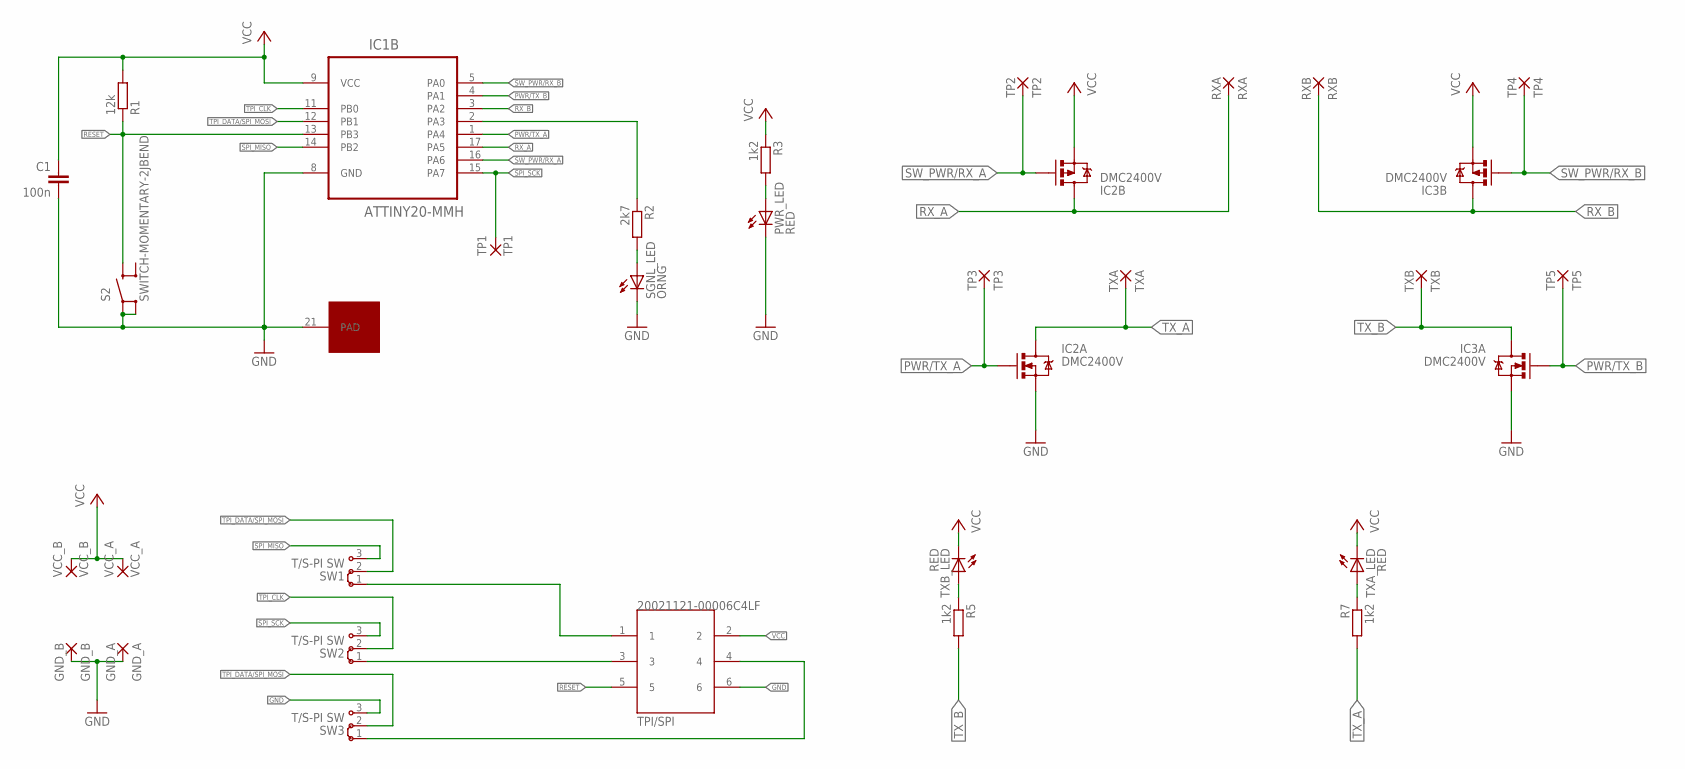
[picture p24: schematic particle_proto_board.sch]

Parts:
C1: 100n; C1206
GND_A: GND_A; 1,6/0,9
GND_B: GND_B; 1,6/0,9
IC1: ATTINY20-MMH; QFN45P300X300X85-21N
IC2, IC3: DMC2400V; SOT563
PWR_LED: RED; SML1206
R1: 12k; R1206
R2: 2k7; R1206
R3, R5, R7: 1k2; R1206
RXA: RXA; 1,6/0,9
RXB: RXB; 1,6/0,9
S2: SWITCH-MOMENTARY-2JBEND; KSC351JLFS
SGNL_LED: ORNG; SML1206
SW1, SW2, SW3: T/S-PI SW; 04C
TP1: TP1; 1,6/0,9
TP2: TP2; 1,6/0,9
TP3: TP3; 1,6/0,9
TP4: TP4; 1,6/0,9
TP5: TP5; 1,6/0,9
TPI/SPI: 20021121-00006C4LF
TXA: TXA; 1,6/0,9
TXA_LED: RED; SML1206
TXB: TXB; 1,6/0,9
TXB_LED: RED; SML1206
VCC_A: VCC_A; 1,6/0,9
VCC_B: VCC_B; 1,6/0,9

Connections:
GND: C1.2, GND_A.1, GND_B.1, IC1.8 (GND), IC1.21 (PAD), IC2.1 (S), IC3.1 (S), PWR_LED.C, S2.1@1 (1), S2.1@2 (1), SGNL_LED.C, SW3.3, TPI/SPI.6
unnamed: SW1.1, TPI/SPI.1
unnamed: SW3.1, TPI/SPI.4
unnamed: R7.1, TXA_LED.A
unnamed: SW2.1, TPI/SPI.3
unnamed: R5.1, TXB_LED.A
unnamed: R2.2, SGNL_LED.A
unnamed: PWR_LED.A, R3.2
unnamed: IC1.2 (PA3), R2.1
PWR/TX_A: IC1.1 (PA4), IC2.2 (G), TP3.1
PWR/TX_B: IC1.4 (PA1), IC3.2 (G), TP5.1
RESET: IC1.13 (PB3), R1.1, S2.2@1 (2), TPI/SPI.5
RX_A: IC1.17 (PA5), IC2.3 (D), RXA.1
RX_B: IC1.3 (PA2), IC3.3 (D), RXB.1
SPI_MISO: IC1.14 (PB2), SW1.3
SPI_SCK: IC1.15 (PA7), SW2.3, TP1.1
SW_PWR/RX_A: IC1.16 (PA6), IC2.5 (G), TP2.1
SW_PWR/RX_B: IC1.5 (PA0), IC3.5 (G), TP4.1
TPI_CLK: IC1.11 (PB0), SW2.2
TPI_DATA/SPI_MOSI: IC1.12 (PB1), SW1.2, SW3.2
TX_A: IC2.6 (D), R7.2, TXA.1
TX_B: IC3.6 (D), R5.2, TXB.1
VCC: C1.1, IC1.9 (VCC), IC2.4 (S), IC3.4 (S), R1.2, R3.1, TPI/SPI.2, TXA_LED.C, TXB_LED.C, VCC_A.1, VCC_B.1

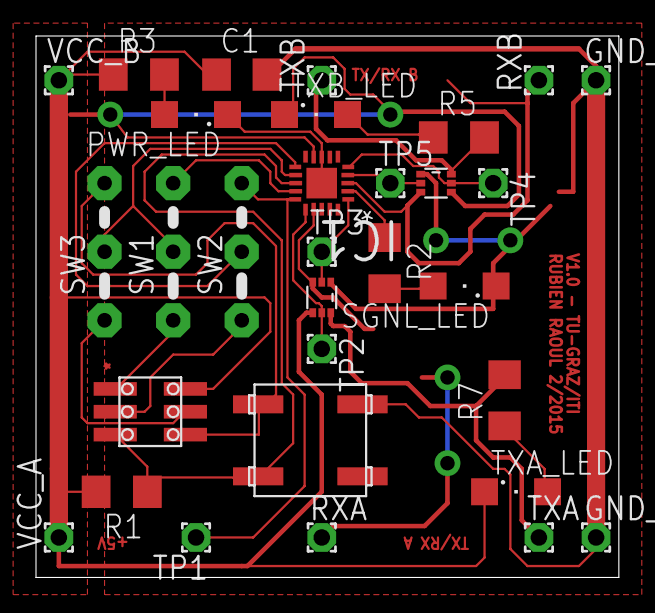
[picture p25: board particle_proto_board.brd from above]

Board: 2 copper layers, 32.4 x 30.1 mm, 31 parts (0 on the bottom side), 23 nets.

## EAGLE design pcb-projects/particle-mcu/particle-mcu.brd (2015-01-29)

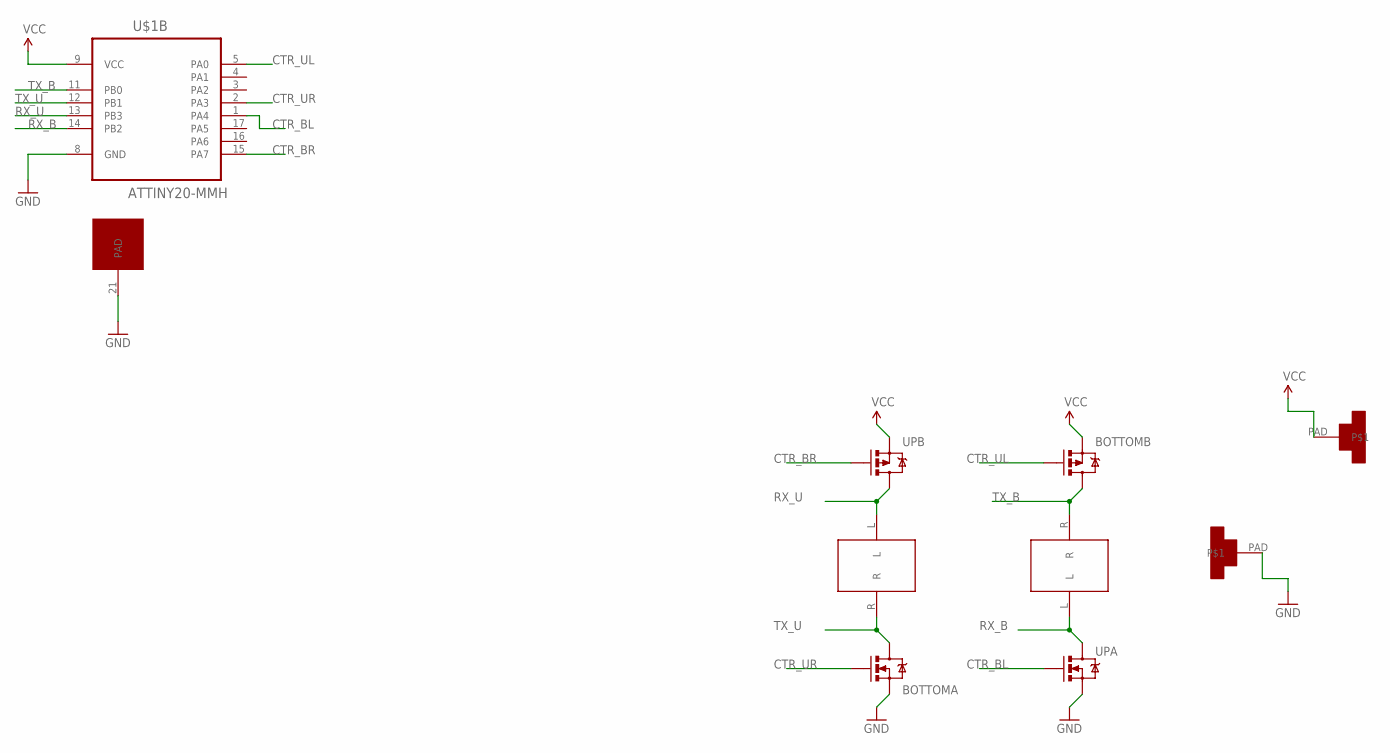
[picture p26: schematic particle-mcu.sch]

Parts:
BOTTOM: DMC2400V; SOT563
U$1: ATTINY20-MMH; QFN45P300X300X85-21N
U$2, U$5: EDGE_PAD; ROUND_EDGE_CONNECTOR
U$3, U$4: SMA-DUAL-CONN4MM; SMA_DOUBLE_PIN2_4MM
UP: DMC2400V; SOT563

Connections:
CTR_BL: U$1.1 (PA4), UP.2 (G)
CTR_BR: U$1.15 (PA7), UP.5 (G)
CTR_UL: BOTTOM.5 (G), U$1.5 (PA0)
CTR_UR: BOTTOM.2 (G), U$1.2 (PA3)
GND: BOTTOM.1 (S), U$1.8 (GND), U$1.21 (PAD), U$5.PAD, UP.1 (S)
RX_B: U$1.14 (PB2), U$4.L, UP.6 (D)
RX_U: U$1.13 (PB3), U$3.L, UP.3 (D)
TX_B: BOTTOM.3 (D), U$1.11 (PB0), U$4.R
TX_U: BOTTOM.6 (D), U$1.12 (PB1), U$3.R
VCC: BOTTOM.4 (S), U$1.9 (VCC), U$2.PAD, UP.4 (S)

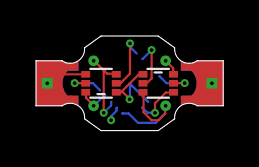
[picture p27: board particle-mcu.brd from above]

Board: 4 copper layers, 10.4 x 5.3 mm, 7 parts (1 on the bottom side), 10 nets.

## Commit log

2015-01-15 added particle project
    [particle_MCU.brd, particle_MCU.sch]
2015-01-19 added initial version of proto pcb
    [particle_proto_board.sch]
2015-01-20 connected h-bridges to comm wires
    [particle_proto_board.brd, particle_proto_board.sch]
2015-01-21 begun with tpi connector
    [particle_proto_board.brd, particle_proto_board.sch]
2015-01-22 begun with routing
    [particle_proto_board.brd, particle_proto_board.sch]
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2015-01-23 added missing track and vcc/gnd holes
    [particle_proto_board.brd]
2015-01-26 replaced packages/library of attiny20 and dmc2400uv
    [particle_proto_board.brd, particle_proto_board.sch]
2015-01-27 close 21, close 22
    [particle_proto_board.brd, particle_proto_board.sch]
2015-01-27 fixes #13
    [particle_proto_board.brd, particle_proto_board.sch]
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2015-01-29 close #26, close #31, close #30, close #28, close #25, close #24, close #23
    [particle_proto_board.brd, particle_proto_board.sch]
2015-01-29 close #27, close #19, close #30,skip / close #18, skip / close #14
    [particle_MCU.brd, particle_proto_board.brd, particle_proto_board.sch]
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2015-01-31 routed board - usable version without filling in gnd/vcc fields
    [particle_proto_board.brd, particle_proto_board.sch]
2015-01-31 fixed some issues, added polygons
    [particle_proto_board.brd]
2015-01-31 filled out vcc/gnd areas
    [particle_proto_board.brd]
2015-02-01 set values to all leds, renamed gnd/vcc pads, TX/RX description beside pads, placed vcc/gnd shunts exposed on schema
    [particle_proto_board.brd, particle_proto_board.sch]
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2015-02-01 fixed typo in schema
    [particle_proto_board.brd, particle_proto_board.sch]
2015-02-02 solved #34, solved #33, solved #32
    [particle_proto_board.brd, particle_proto_board.sch]
2015-02-02 added several sparkfun and one samtec library, fixed #39, fixed #37, fixed #36, fixed #35, fixed #29
    [particle_proto_board.brd, particle_proto_board.sch]
2015-02-03 fixed #41, fixed #40, fixed #39, fixed #37, fixed #35, fixed #29
    [particle_proto_board.brd, particle_proto_board.sch]
2015-02-04 routed board after several changes to schema
    [particle_proto_board.brd, particle_proto_board.sch]
2015-02-04 closed #44, closed #43, closed #42
    [particle_proto_board.brd, particle_proto_board.sch]
2015-02-05 renamed parts in schema
    [bom-ex.cfg, particle_proto_board.brd, particle_proto_board.sch]
2015-02-06 fixed #47
    [particle_proto_board.brd, particle_proto_board.sch]
2015-02-08 corrected version number
    [particle_proto_board.brd]
2015-02-08 created library for several smt switches (rs components)
    [particle_proto_board.brd, particle_proto_board.sch]
2015-02-09 routed board with rs components
    [particle_proto_board.brd, particle_proto_board.sch]
2015-02-09 added missing wire
    [particle_proto_board.brd]
2015-02-10 changed 90° spi connector to straight one
    [particle_proto_board.brd, particle_proto_board.sch]
2015-02-10 fixed wrong tpi/spi-switch configuration matrix on schema
    [particle_proto_board.brd, particle_proto_board.sch]
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2015-02-10 changed all resistors 1k -> 150
    [particle_proto_board.brd, particle_proto_board.sch]
2015-02-11 cosmetics: moved 5V label and testpoint 1 smome mm
    [particle_proto_board.brd, particle_proto_board.sch]
2015-02-11 enhanced switch: now has 4 terminals - polygon filling now makes termal pad correct
    [particle_proto_board.brd, particle_proto_board.sch]
2015-02-12 successfully connected four tiny airwires below pads
    [particle_proto_board.brd, particle_proto_board.sch]
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2015-02-19 created a reflow profile for the tug oven
    [max-heat-curve.csv, min-heat-curve.csv, real-heat-curve.csv]
2015-02-25 highlighted design error on schema regarding tx-leds
    [particle_proto_board.brd, particle_proto_board.sch]
2015-03-01 fixed #52, fixed #53, fixed #54, fixed #57
    [particle_proto_board.brd, particle_proto_board.sch]
2015-05-05 soldering oven heat curves
    [real-heat-curve.csv]
2015-09-28 added reflow temperature curves
    [real-heat-curve-board1.csv, real-heat-curve-board2.csv, real-heat-curve-board3.csv]
2015-12-22 removed led on rx due to damping signal issue
    [particle_proto_board.brd, particle_proto_board.sch]
2016-01-04 added particle sketch created with kicad
    [led-smd-1206.fcstd, particle.kicad_pcb, particle.sch]
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2016-01-06 re-routed smaller pcb, added several 3d packages, min. fix in schema
    [lightbulb-3x6.fcstd, particle.kicad_pcb, particle.sch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]
2016-01-06 added all 3d models, pcb cosmetics
    [lightbulb-3x6.fcstd, particle.kicad_pcb, particle.sch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]
2016-01-06 increased clearance from 0.2mm to 0.33mm
    [particle.kicad_pcb]
2016-01-08 added bill of material
    [particle.sch, particle_bom.csv]
2016-01-09 added usb connector module/3d
    [particle.kicad_pcb, particle_bom.csv, usb-multicomp.fcstd]
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2016-01-10 added array header and tail
    [_saved_particle-tiny1634-array-tail.sch, particle-tiny1634-array-header.kicad_pcb, particle-tiny1634-array-header.sch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]
2016-01-27 minor edge cut alignment, added particle array
    [particle-tiny1634-array-header.kicad_pcb, particle-tiny1634-array-tail.kicad_pcb, particle.kicad_pcb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]
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2016-01-29 added board with lead
    [particle-tiny1634-plugable-module-with-lead.kicad_pcb]
2016-01-30 run cleaned up on pcbs
    [particle-tiny1634-plugable-module-with-lead.kicad_pcb, particle-tiny1634-plugable-module.kicad_pcb]
2016-01-30 added euro-pcb with multiple modules placed on it
    [euro-pcb.kicad_pcb]
2016-01-31 remved no-net zones, refined gnd zone
    [particle-tiny1634-plugable-module-with-lead.kicad_pcb]
2016-01-31 added power supply capacitor
    [particle-tiny1634-plugable-module-with-lead.kicad_pcb, particle-tiny1634-plugable-module.sch]
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2016-02-01 minor change: updated MCU power supply decoupling and euro pcb
    [euro-pcb.kicad_pcb, particle-tiny1634-plugable-module-with-lead.kicad_pcb]
2016-02-03 removed mistakenly exported grid planes
    [led-smd-1206.fcstd, pin-header-254mm.fcstd]
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2016-02-03 added grid board visualization
    [grid-board-particle-connector.fcstd, proto-pcb-gridboard-vis.fcstd]
2016-02-03 added mosfet-sma-connection example schema
    [particle-tiny1634-plugable-module.sch]
2016-02-04 added grid board sketch
    [proto-pcb-gridboard-sketch.fcstd]
2016-02-04 refined grid board: cutouts
    [proto-pcb-gridboard-sketch.fcstd]
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2016-02-04 change shape, updated euro pcb
    [euro-pcb.kicad_pcb, particle-tiny1634-plugable-module-with-lead.kicad_pcb]
2016-02-04 updated grid board sketch
    [proto-pcb-gridboard-sketch.fcstd]
2016-02-08 grid board illustration is now in grey
    [particle-tiny1634-plugable-module-with-lead.kicad_pcb, proto-pcb-gridboard-sketch.fcstd]
2016-02-08 added particle v1.1 array
    [array-euro-pcb.kicad_pcb, particle-array.kicad_pcb]
2016-07-20 changed network names slightly
    [particle-tiny1634-plugable-module.sch]
2016-08-03 cleanup folders; minimal pcb changes
    [euro-pcb.kicad_pcb, particle-tiny1634-plugable-module-with-lead.kicad_pcb, particle-tiny1634-plugable-module.kicad_pcb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]
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2016-08-07 restored tx bridge example schema
    [sma-comm-bridge-example.sch]

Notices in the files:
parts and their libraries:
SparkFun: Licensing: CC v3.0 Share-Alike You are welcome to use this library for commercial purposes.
